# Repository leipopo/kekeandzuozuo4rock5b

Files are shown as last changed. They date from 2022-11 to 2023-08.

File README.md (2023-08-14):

# kekeandzuozuo4rock5b 

## CAD源文件，链接 https://a360.co/3OjdNzo

## 给RockPi 5B V1.4硬件版本用的壳壳 （模型以CAD文件为准,stl可能更新不及时）

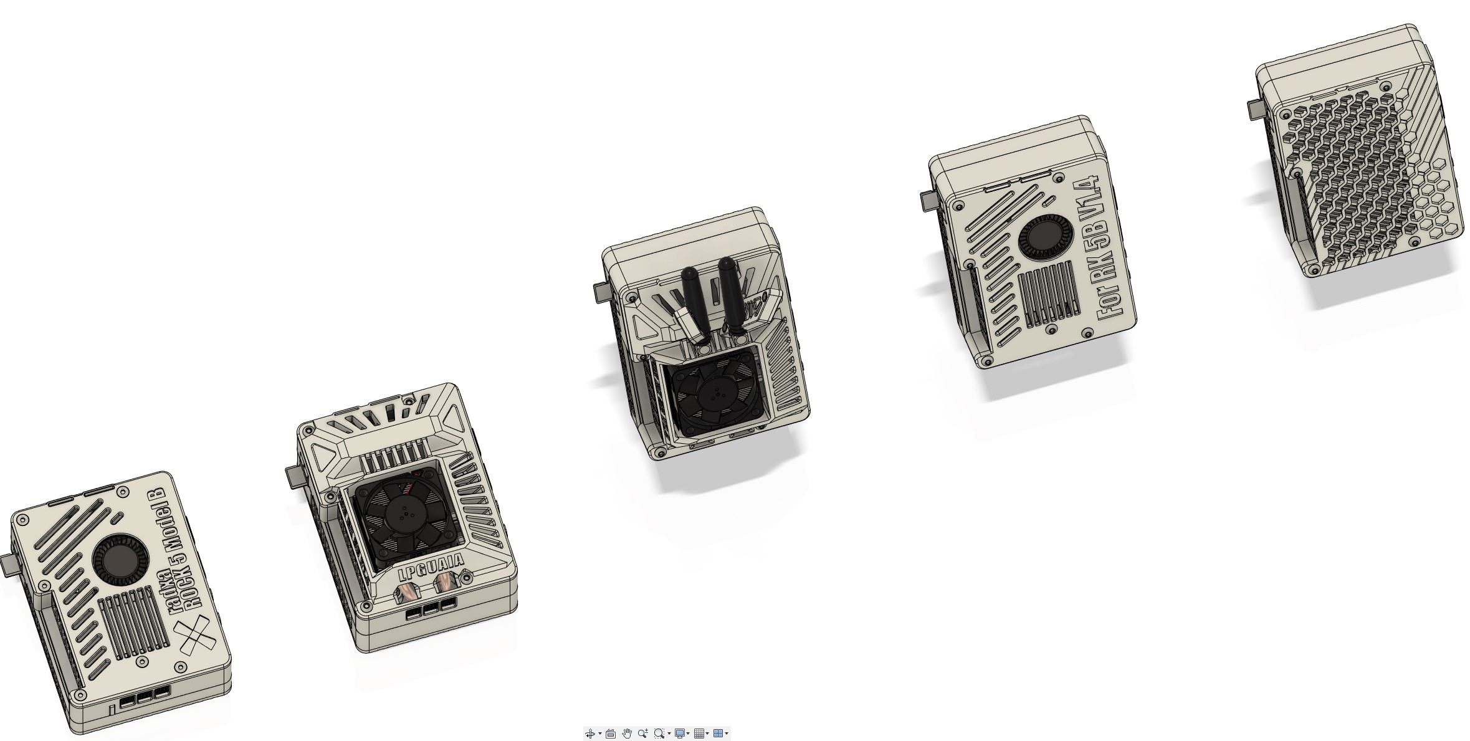
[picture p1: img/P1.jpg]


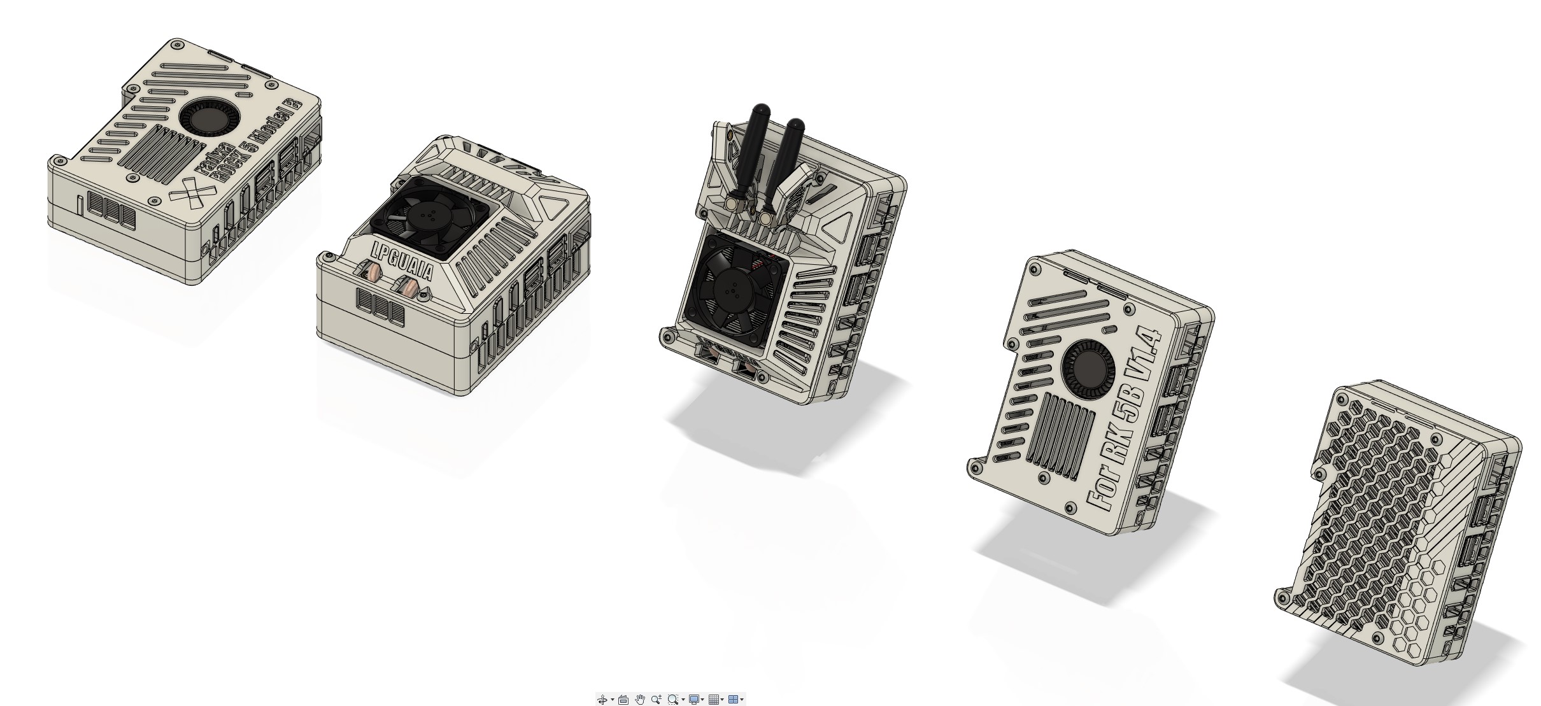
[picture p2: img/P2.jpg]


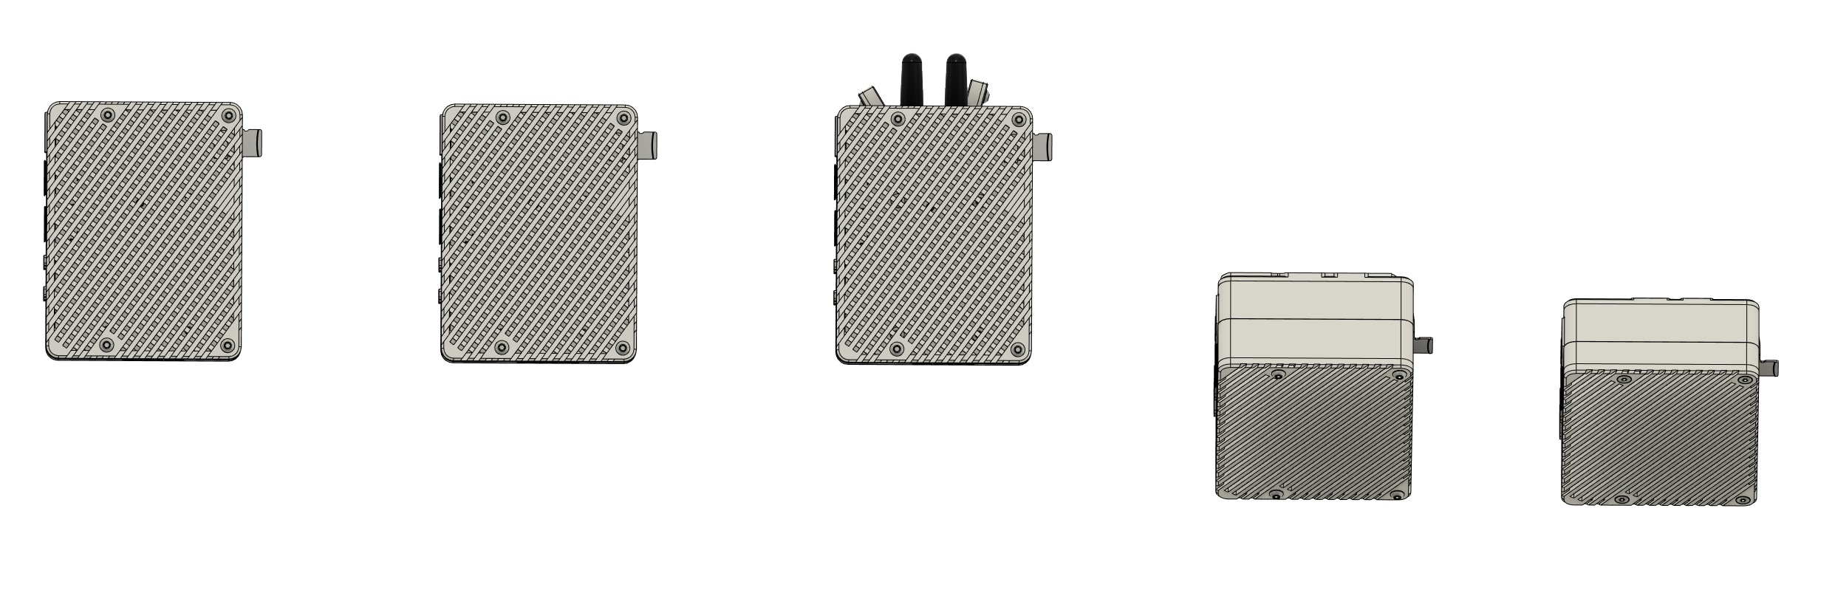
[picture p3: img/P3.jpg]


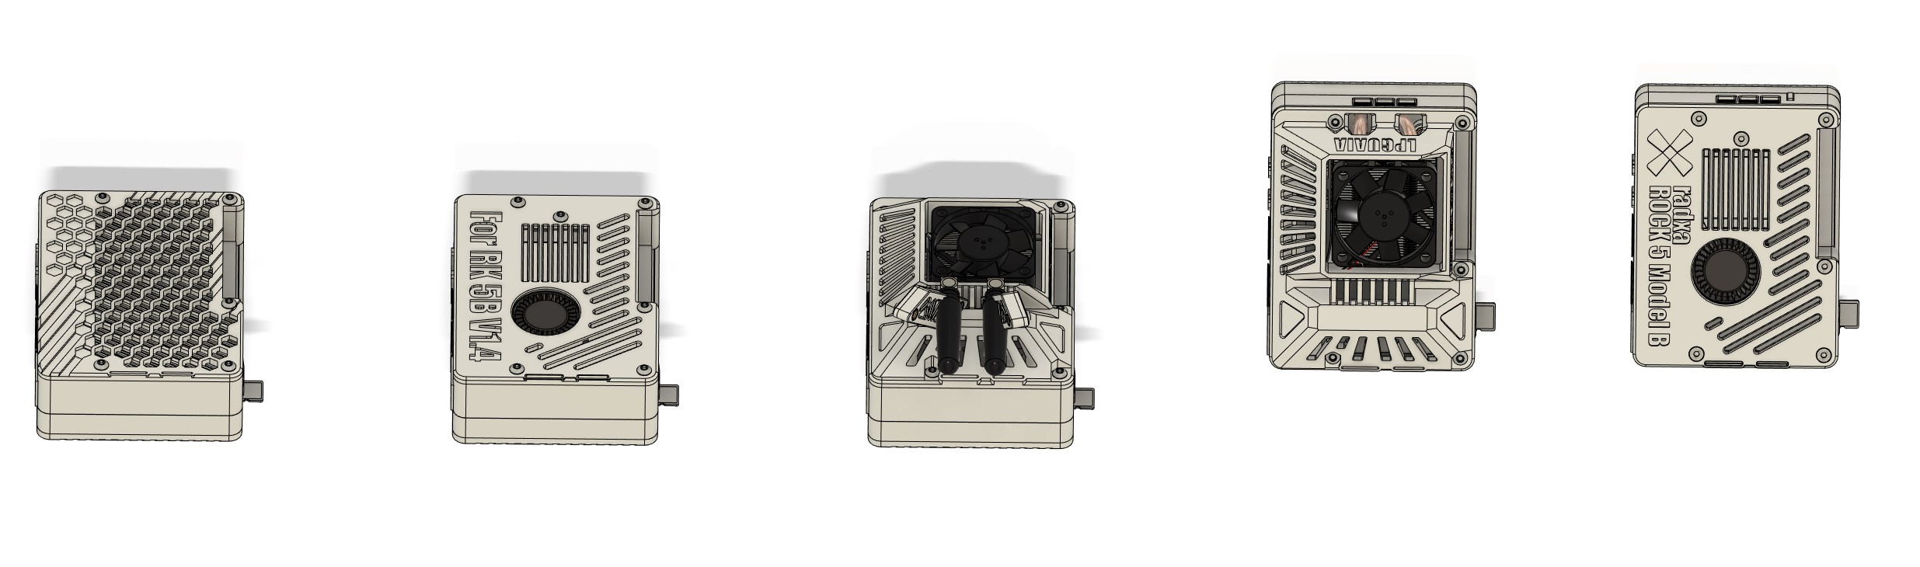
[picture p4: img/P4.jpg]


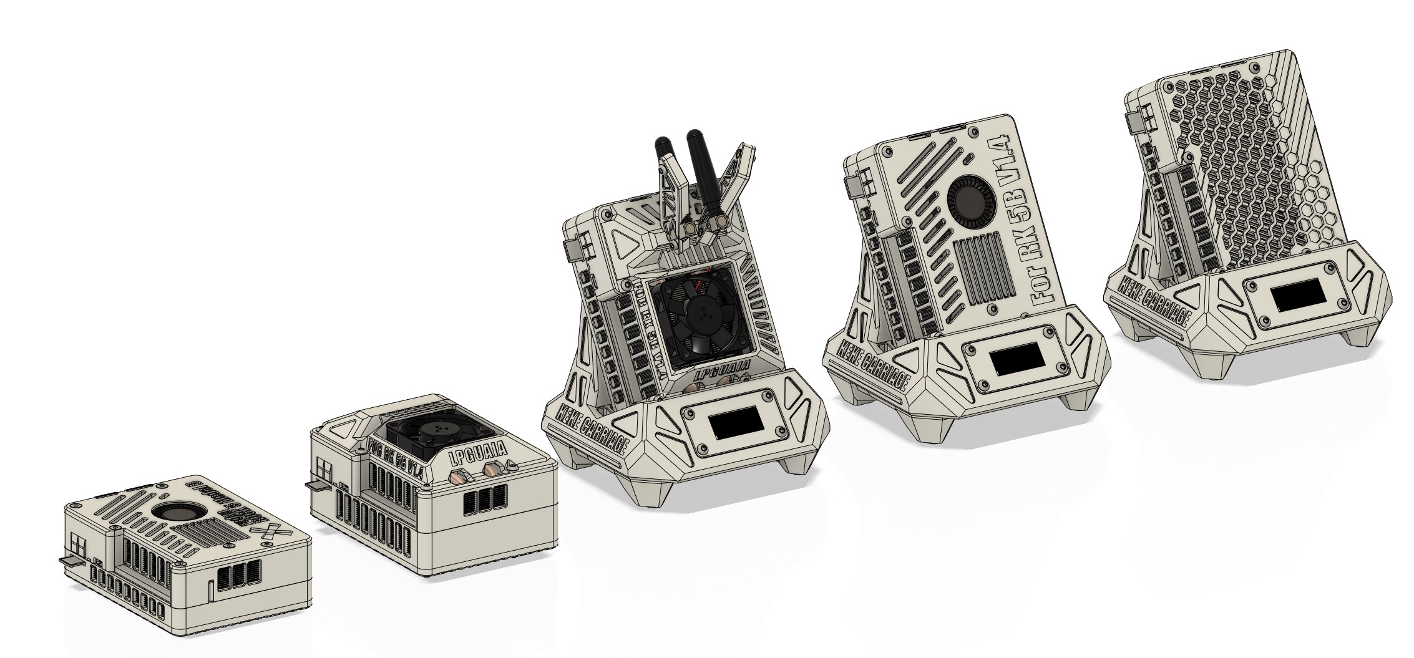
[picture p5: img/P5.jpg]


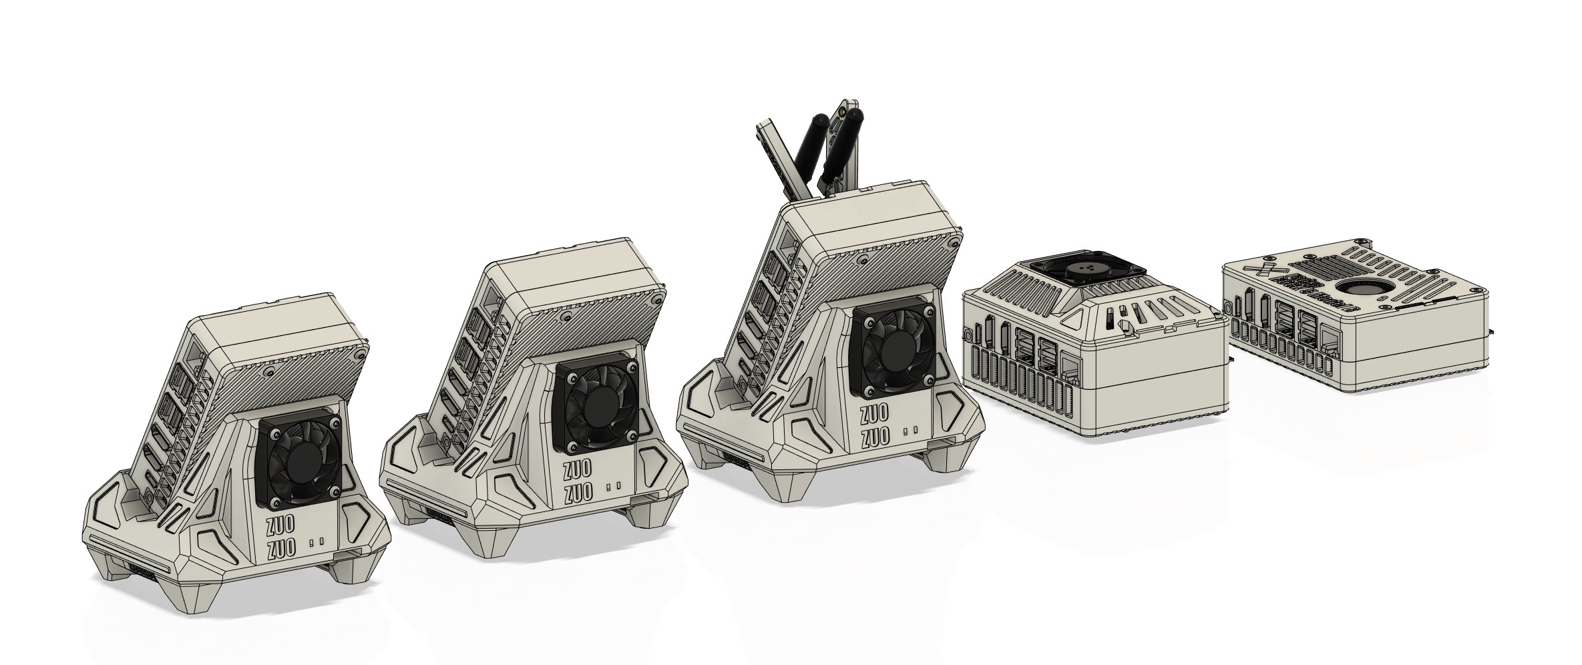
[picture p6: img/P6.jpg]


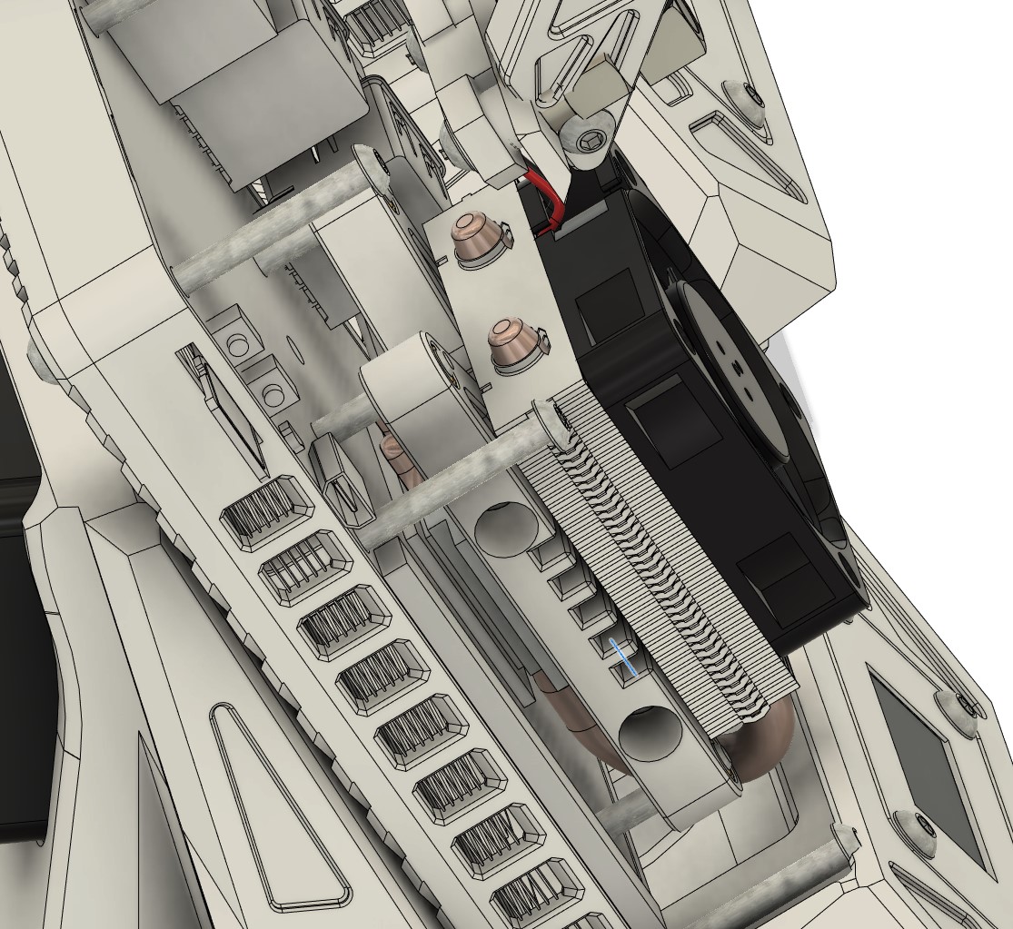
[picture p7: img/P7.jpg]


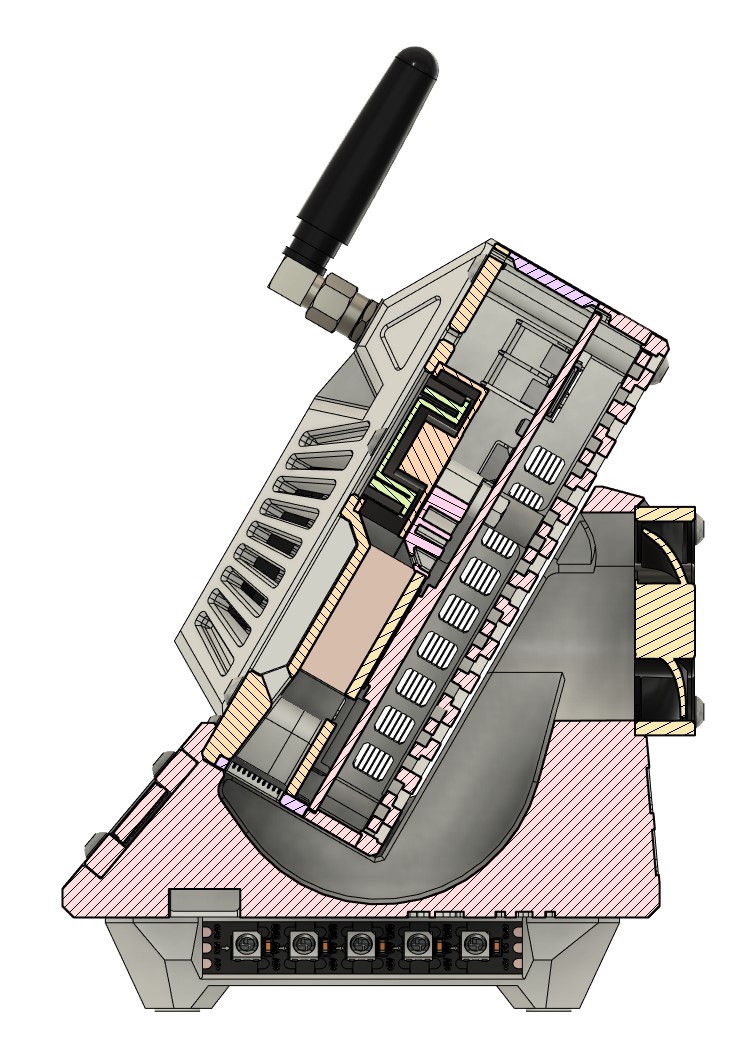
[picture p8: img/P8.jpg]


买不起台灯不太好打光就举着拍吧

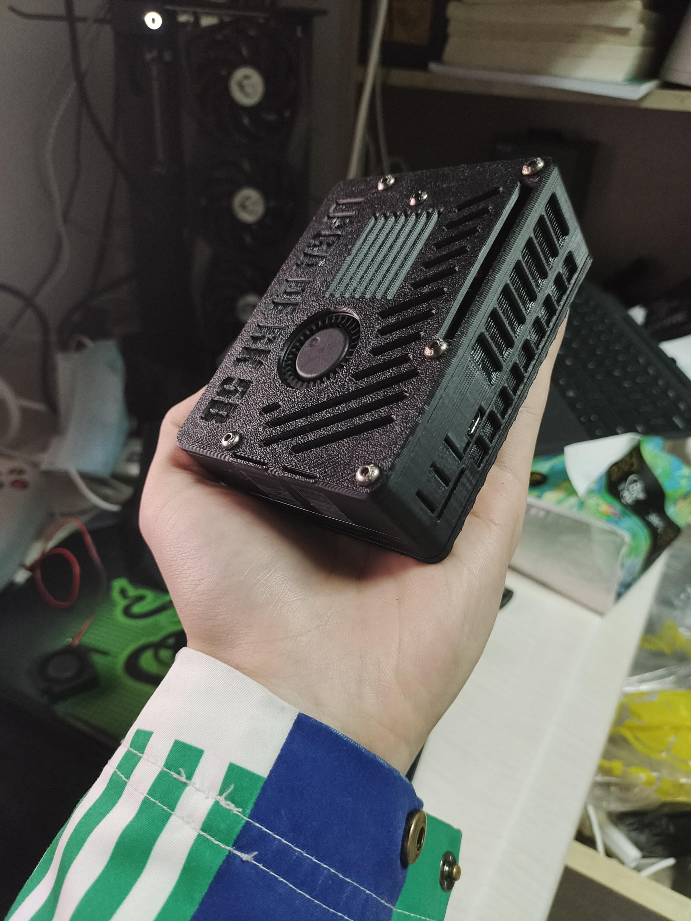
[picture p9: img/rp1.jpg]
rp1 图


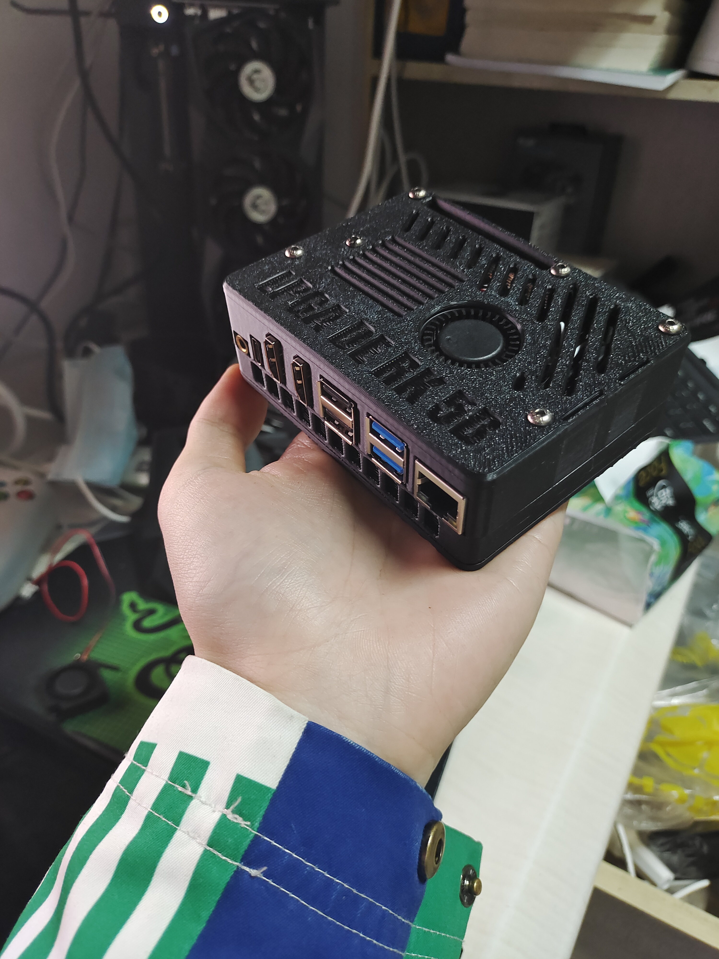
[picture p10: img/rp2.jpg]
rp2 图


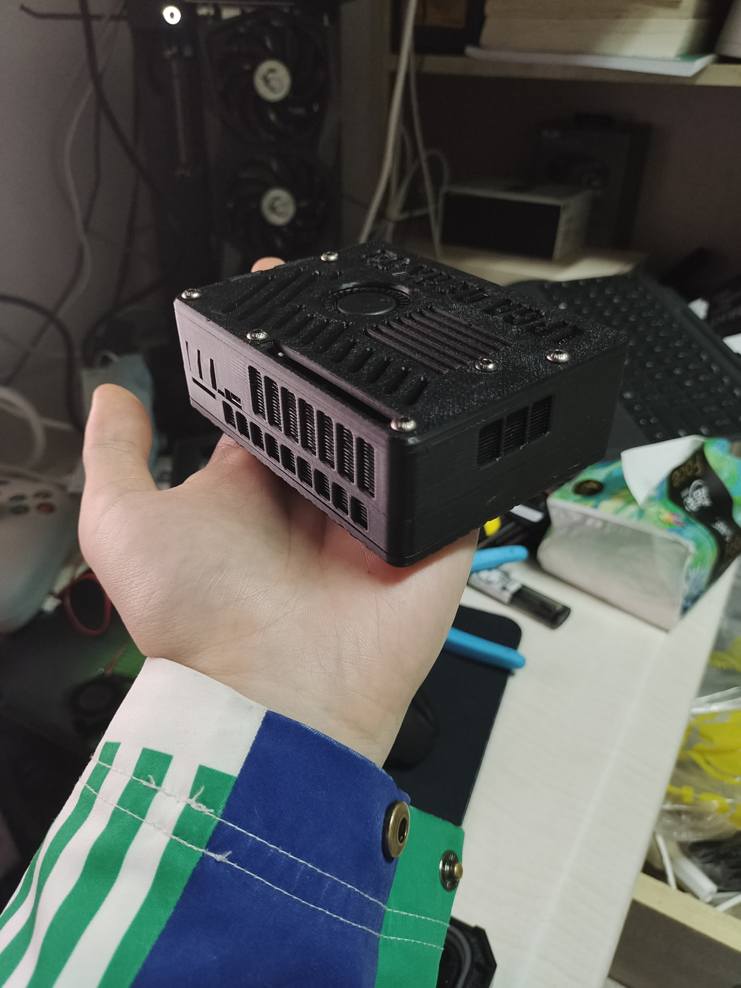
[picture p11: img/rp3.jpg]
rp3 图


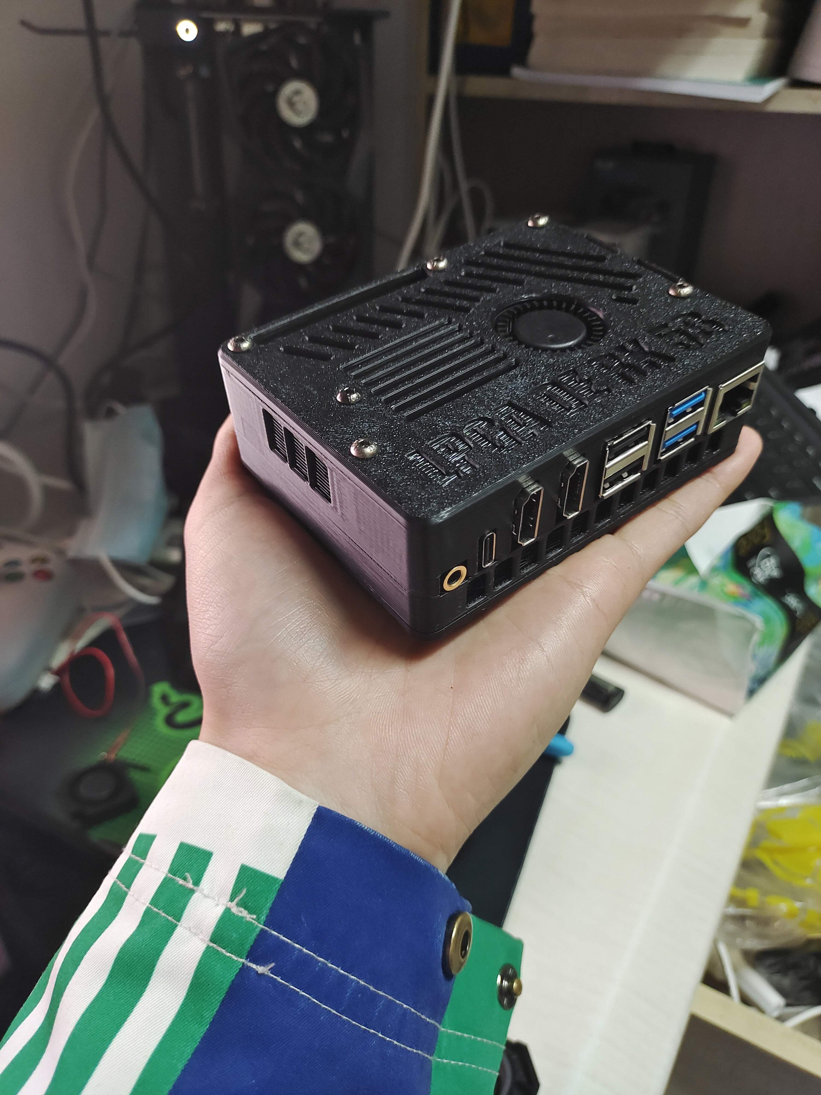
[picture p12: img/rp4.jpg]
rp4 图


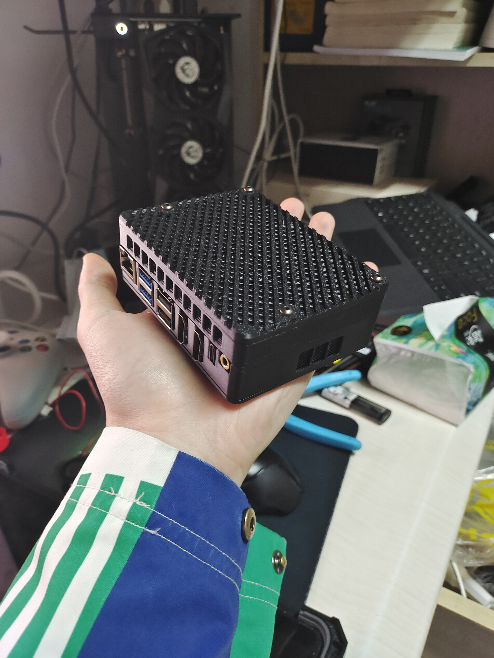
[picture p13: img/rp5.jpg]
rp5 图


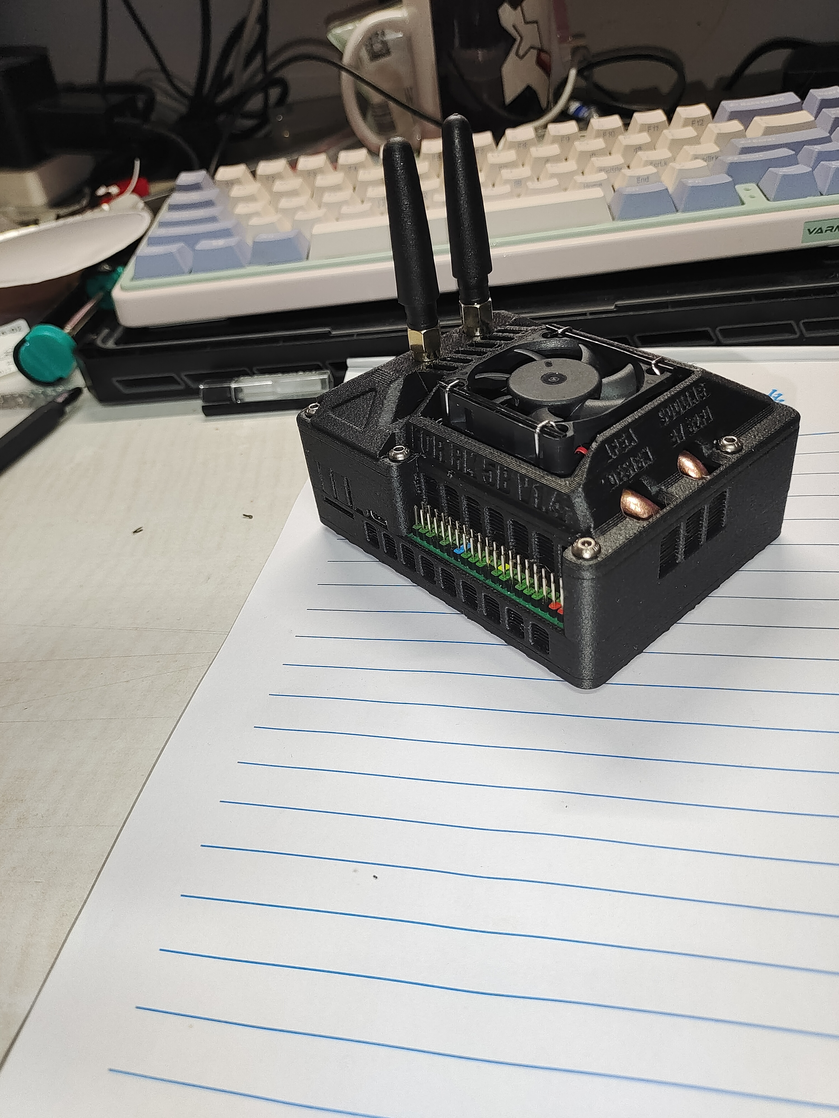
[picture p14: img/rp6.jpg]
rp6 图


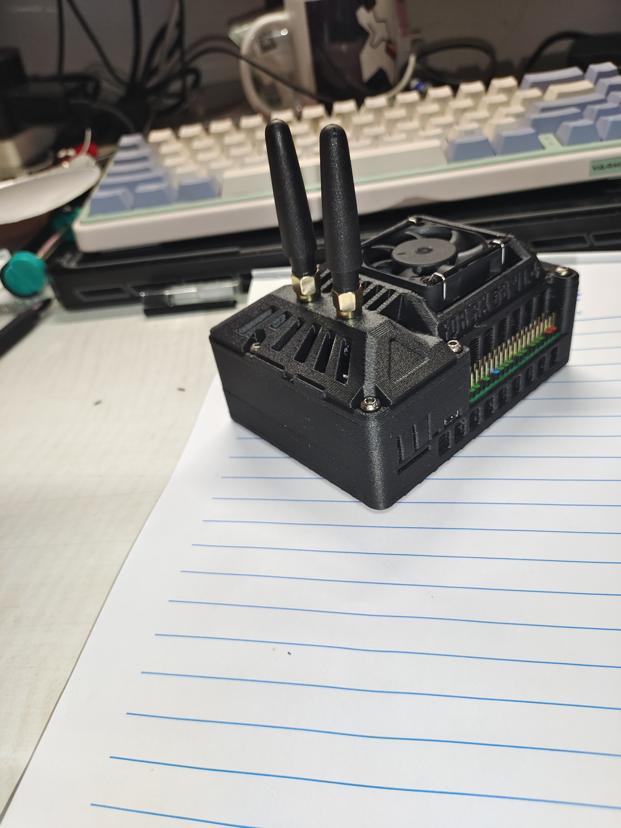
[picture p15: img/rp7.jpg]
rp7 图


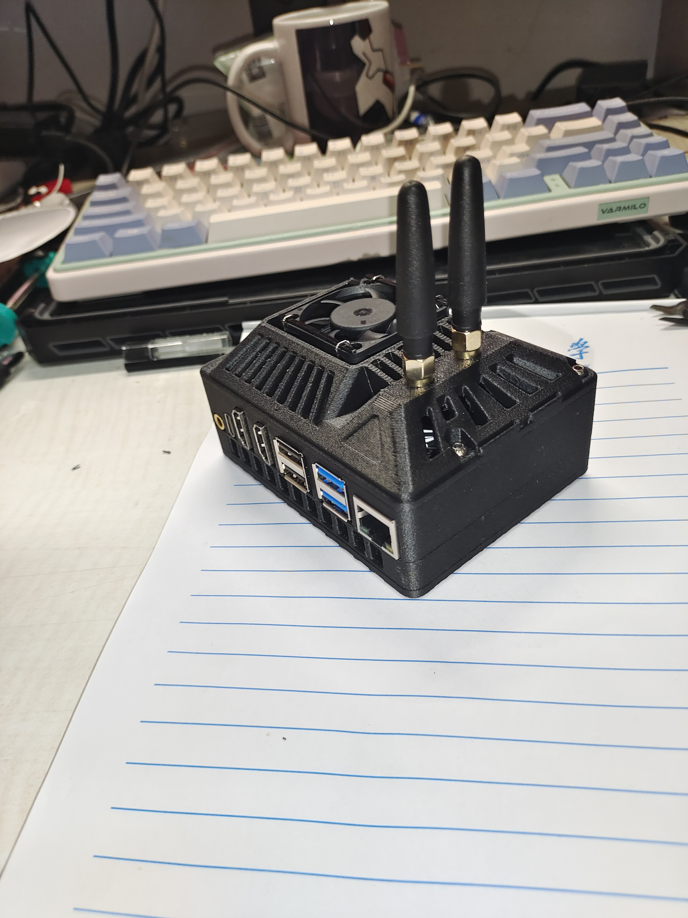
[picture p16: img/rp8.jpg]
rp8 图


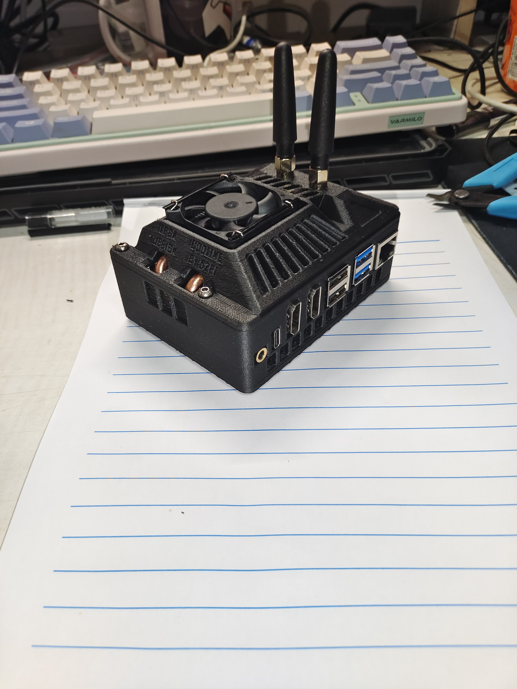
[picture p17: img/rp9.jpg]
rp9 图


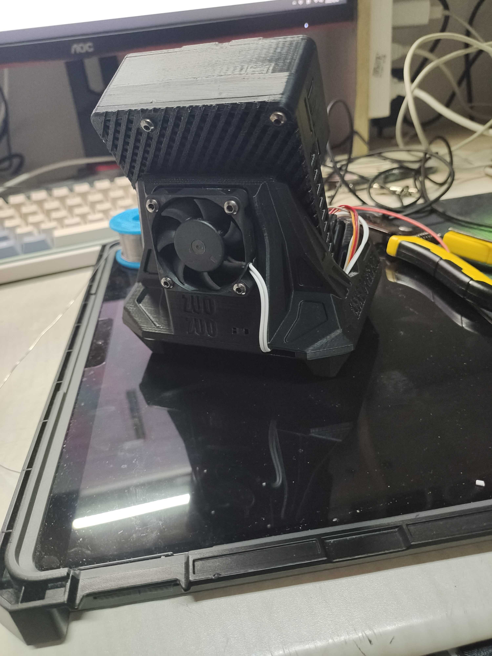
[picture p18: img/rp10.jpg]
rp10 图


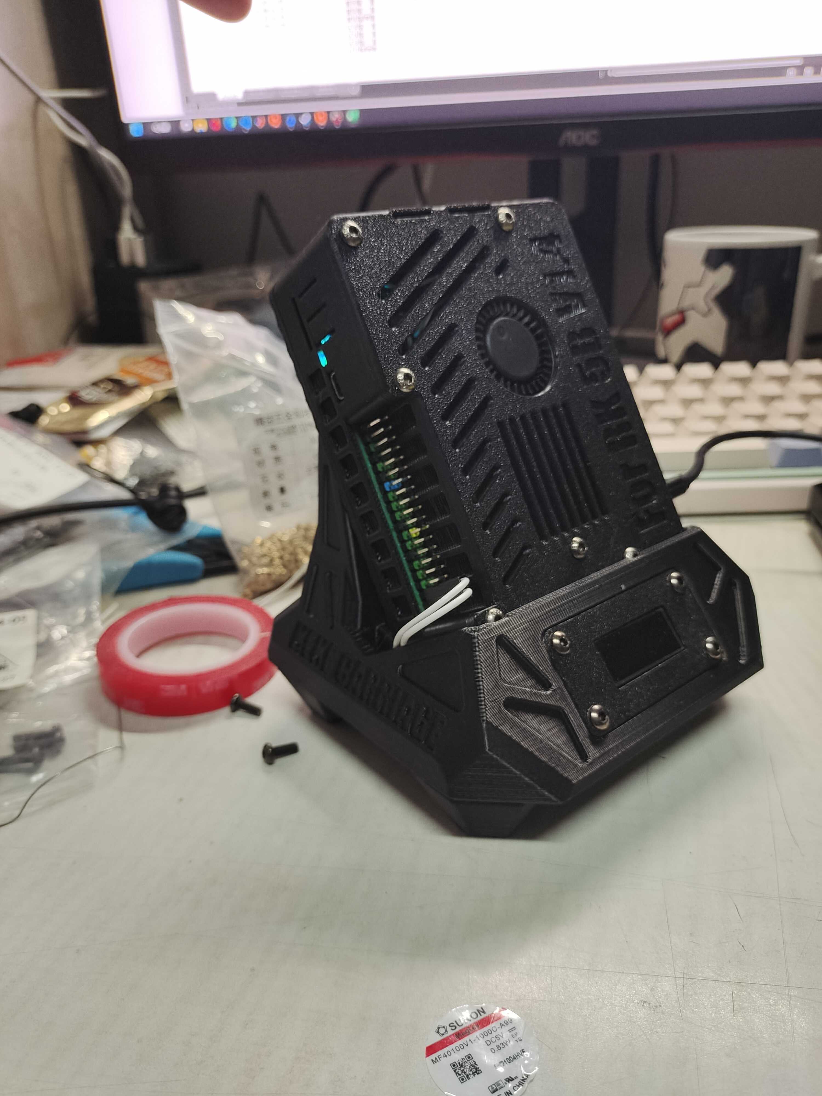
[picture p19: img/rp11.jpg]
rp11 图


## 物料购买注意事项

1. 散热鳍片25x25x11；

2. 滚花螺母尺寸M3 H4 D4.5
滚花螺母尺寸M3 H4 D4.5
滚花螺母尺寸M3 H4 D4.5
重要的事情嗦三遍（用外径5的大了容易顶到附近的小电容）；

3. 螺丝M3 长度8——25买齐 还需要一个六角螺母（散热片版本）；

4. 摄像头，屏幕，GPIO排针都需要线材引出；

5. 除了下压式散热版本，其他版本无线网卡需要用粘上去的那种天线；

6. 散热片版本如果使用硅脂导热，需要购买3M的VHB双面胶贴在上盖压住散热片的位置，如上面最后一张图红色部分所示。屏幕的固定同样需要VHB，因为我担心这个小屏幕尺寸公差比较大所以游隙留的比较大；

7. WS2812灯条买100灯珠一米的，贴在脚撑内侧空白处，两侧的串联，应该可以一边五个，CAD图里用的60灯珠的示意一下；

8. 需要脚垫可淘宝搜索“橡胶脚垫 机箱仪器”，然后买内径3mm外径11mm及以下的如下图

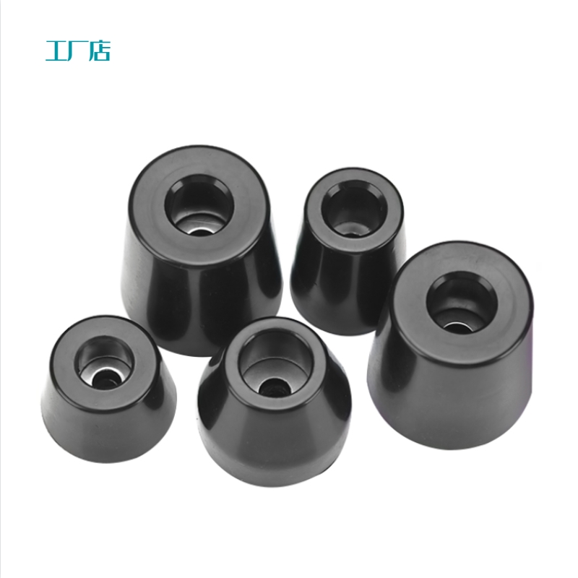
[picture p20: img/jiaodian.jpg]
脚垫图


## FDM注意事项（实时更新，0.4线宽，0.2层高）

使用壳壳需要打印“壳壳基础打印件”中的“上框”、“下框”、“下盖”或者“壳壳基础打印件”中“改件”中的同名文件。此外还需要根据购买的散热组件来打印相应的其他结构,stl文件分别放置在“散热片散热”、“官方散热器散热”以及“下压式散热”中。

树莓派上盖有有外置天线/无外置天线两个版本，有天线上盖可以上小耳朵或者盖板代替外置天线，小耳朵里面可以塞一个内置天线

带maskrom按钮的上框略有突起但也可以放上底座

## 关于风扇脚本（自用）

需要sudo权限，要自启的话需要自行操作一下。

拉取完整仓库：

```cd ~```

```git clone https://ghproxy.com/https://github.com/leipopo/kekeandzuozuo4rockpi5b```

运行风扇脚本：

```cd $HOME/kekeandzuozuo4rockpi5b/ctrlscript/fanctrl/build```

```sudo ./fanctrl```

### 调整风扇初始化文件参数

不建议修改此文件排版

### 参数命名及作用

![风扇原理示意图](/img/fan.jpg "风扇原理示意图")

1. reset 调整参数后需要调整此参数为1

2. obj 温控对象，暂时只有soc

3. exp_temp 期望温度

4. wall_temp 上限温度

5. lowpower_temp 进入低速区温度

6. fanon_temp 风扇开启温度
 
7. fan_maxpwm 风扇极限转速时pwm占空值

8. fan_minpwm 风扇起转时的pwm占空值

9. fan_maxpower 风扇最大功率 0--1.f

10. fan_mod 1.线性控制，2.手动控制 3.开关控制
 
11. fan_pwm="0" 手动控制时给的pwm占空值

12. pwm_period="10000" pwm周期值

13. pwm_chip="/pwmchip15" pwm设备号

14. pwm_channel="/pwm0" pwm设备下通道号

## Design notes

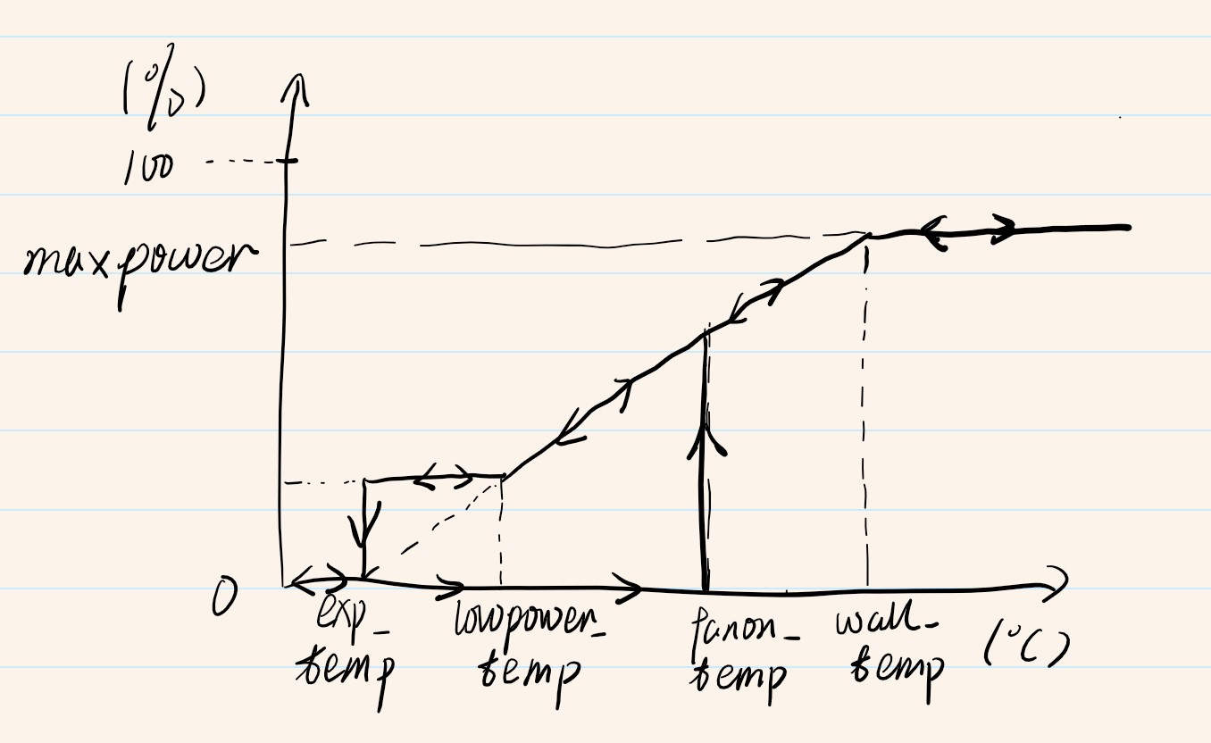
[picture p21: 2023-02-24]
img/fan.jpg

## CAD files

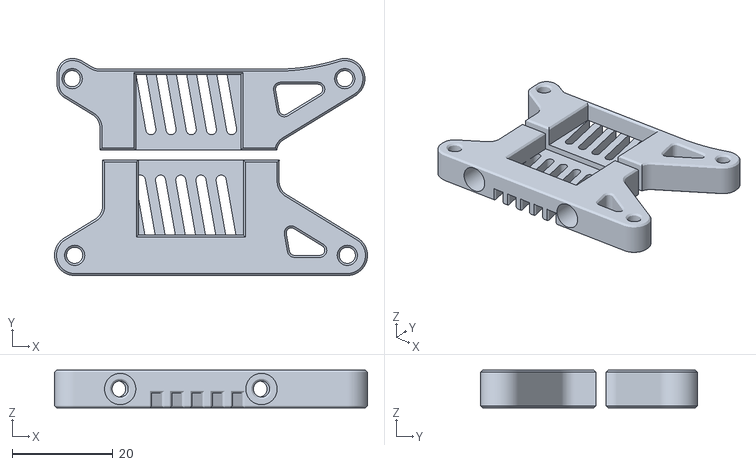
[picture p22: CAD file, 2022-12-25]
stl/下压式散热/扣具.stl
62.0 x 43.0 x 7.50

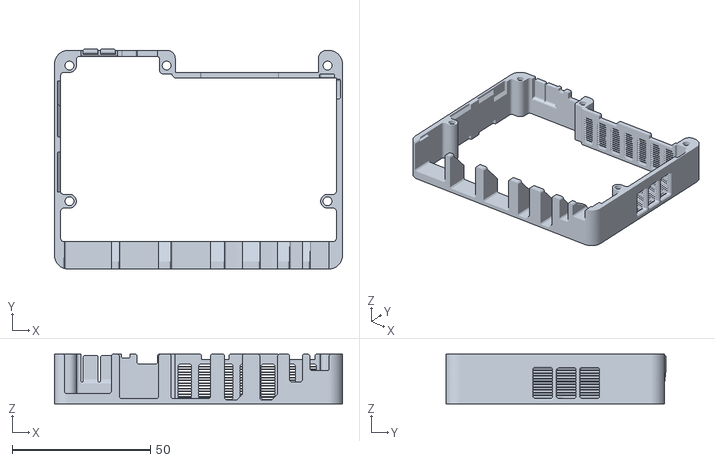
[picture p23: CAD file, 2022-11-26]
stl/壳壳基础打印件/上框.stl
104.0 x 79.5 x 18.0

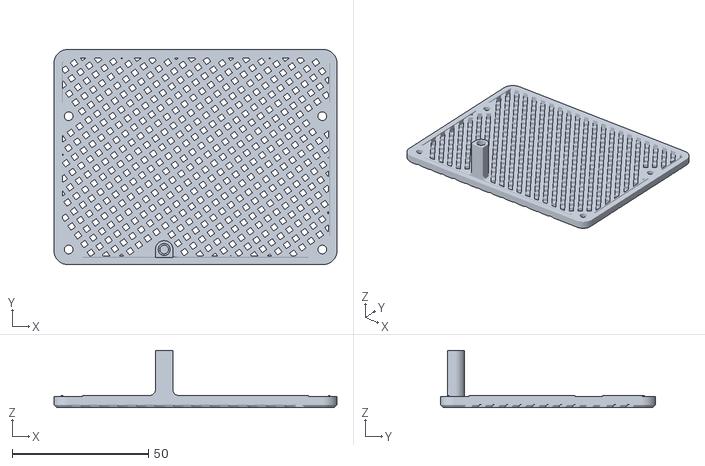
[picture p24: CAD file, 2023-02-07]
stl/壳壳基础打印件/改件/下盖加高.stl
104.0 x 79.0 x 21.0

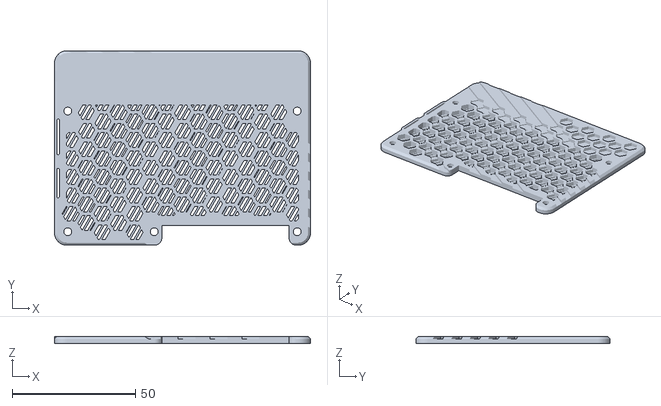
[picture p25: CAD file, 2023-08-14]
stl/官方散热器散热/上盖FE_密集网格.stl
104.0 x 79.0 x 3.00

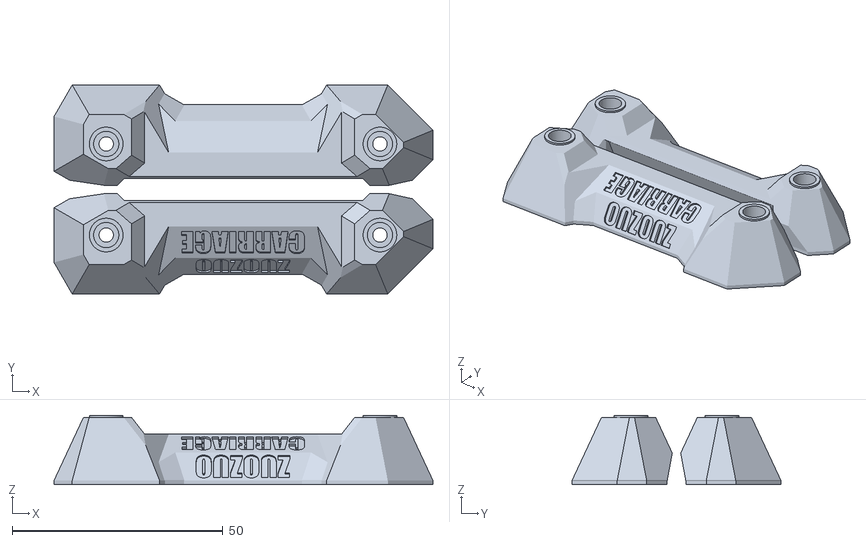
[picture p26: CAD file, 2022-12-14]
stl/座座/rgb脚撑.stl
90.0 x 49.6 x 16.5

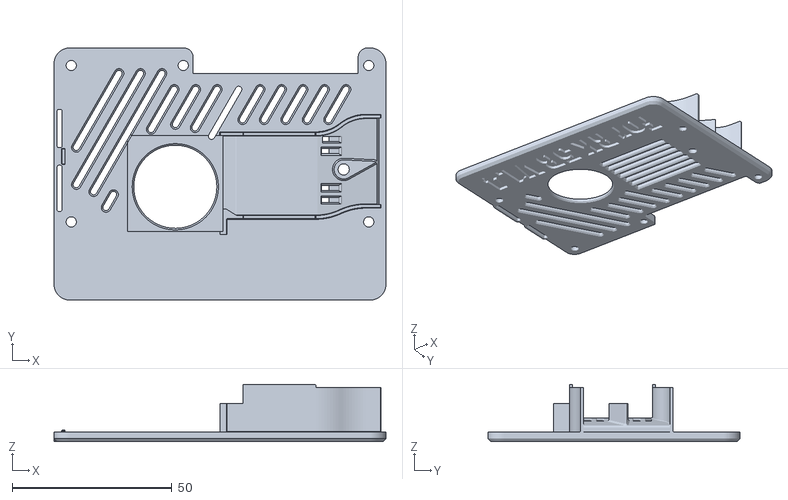
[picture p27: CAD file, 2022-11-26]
stl/散热片散热/上盖.stl
104.0 x 79.0 x 18.0

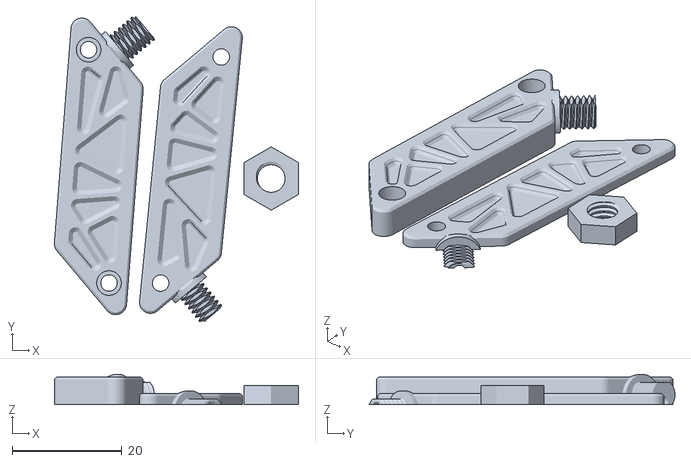
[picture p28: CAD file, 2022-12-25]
stl/下压式散热/耳朵.stl
44.6 x 55.8 x 5.50

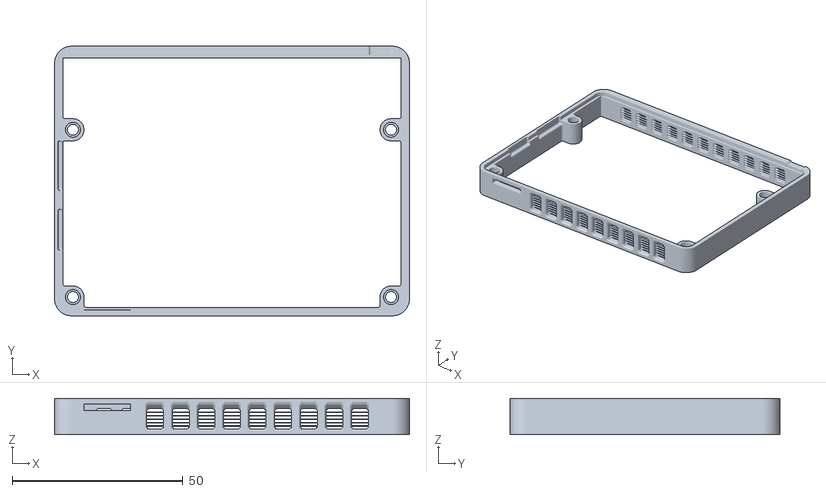
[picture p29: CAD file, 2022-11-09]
stl/壳壳基础打印件/下框.stl
104.0 x 79.0 x 10.6

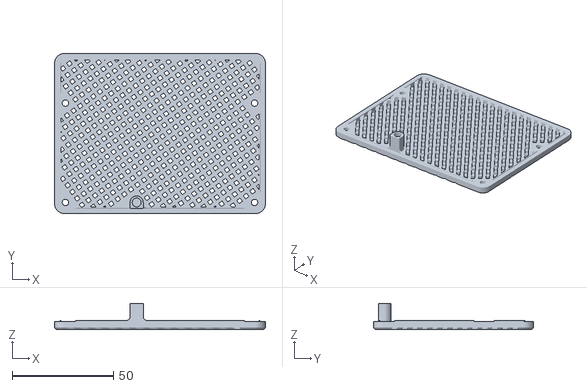
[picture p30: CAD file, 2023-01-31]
stl/壳壳基础打印件/改件/下盖沉头螺丝版本.stl
104.0 x 79.0 x 13.0

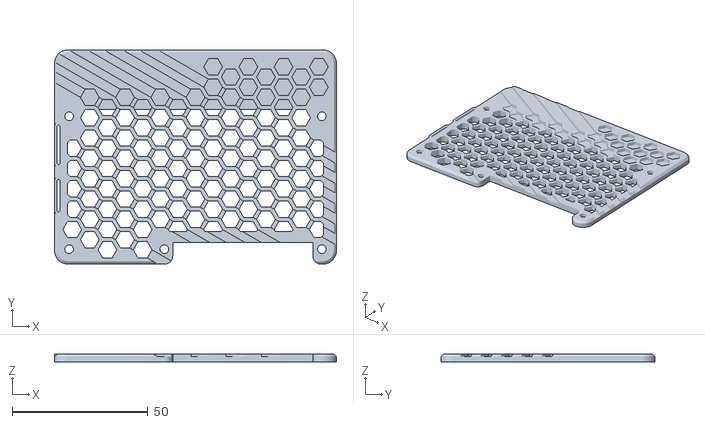
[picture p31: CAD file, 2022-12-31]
stl/官方散热器散热/上盖FE.stl
104.0 x 79.0 x 3.00

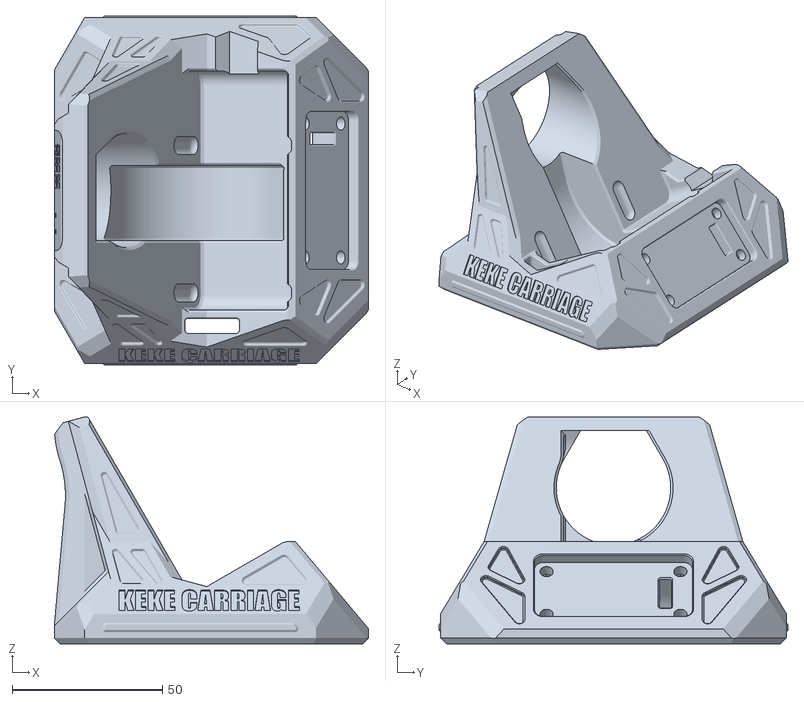
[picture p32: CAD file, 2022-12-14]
stl/座座/底座.stl
104.5 x 116.0 x 75.4

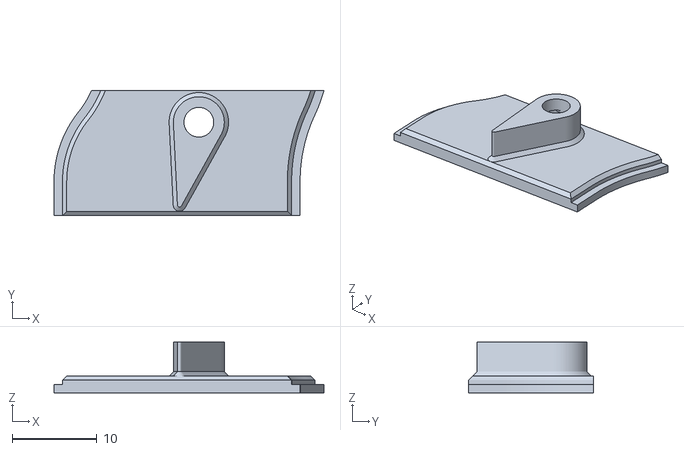
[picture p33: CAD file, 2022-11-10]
stl/散热片散热/风道下挡板.stl
31.8 x 14.8 x 6.00

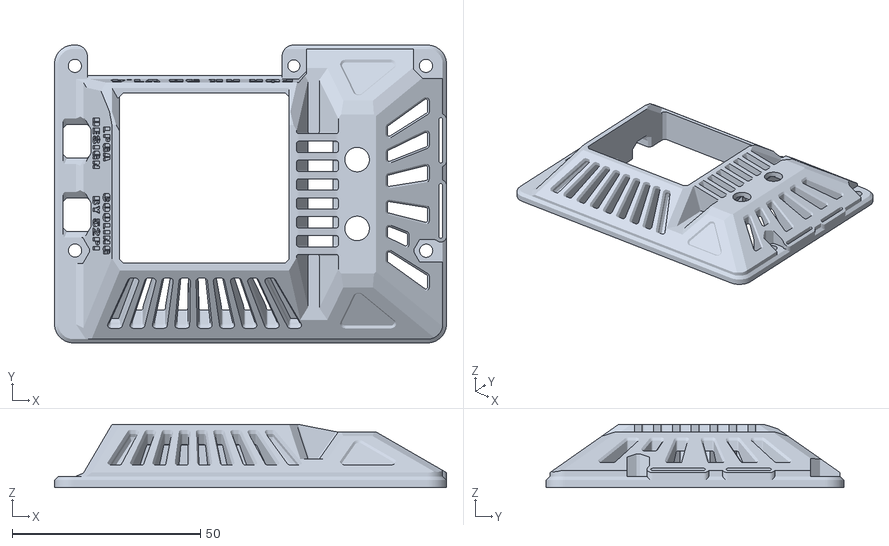
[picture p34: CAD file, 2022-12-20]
stl/下压式散热/上盖.stl
104.0 x 79.0 x 16.8

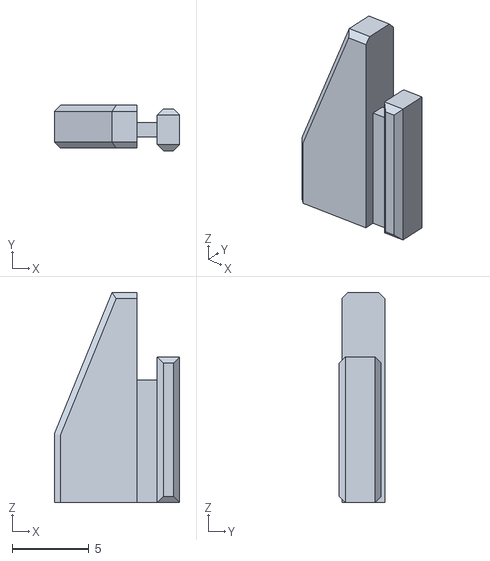
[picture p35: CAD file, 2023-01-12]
stl/壳壳基础打印件/改件/maskrom按钮.stl
8.18 x 2.97 x 13.7

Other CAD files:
stl/散热片散热/改件/上盖沉头螺丝版本.stl
stl/壳壳基础打印件/下盖.stl
stl/座座/屏幕盖.stl
stl/散热片散热/风扇座.stl
stl/壳壳基础打印件/改件/上框withmaskrom按钮.stl
stl/壳壳基础打印件/改件/下框加高.stl

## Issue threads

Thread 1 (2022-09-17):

能增加一个0.96寸oled位置吗

FantasyGmm, 2022-09-17:
能不能加个0.9寸长条oled的屏位置啊，可以显示一些信息，程序方便等我板子到手了我可以写一个
用蓝图风扇噪音大不大啊，之前买过动平衡很差，噪音很大，直接丢了

leipopo, 2022-09-17:
屏幕等我淘宝一下看看具体尺寸，应该也许能加但是线肯定不会太好走。鹏达蓝图的低转速3010不太行，要静音的话换一家吧。（我又买了12k转的过两天到了试试

leipopo, 2022-09-17:
能加但是线不会太好走。鹏达蓝图的低转速3010不太行，要静音的话就换一家吧。（我又买了12k转的过两天到了试试

leipopo, 2022-09-17:
我试试在上盖加一个，应该问题不大。

FantasyGmm, 2022-09-18:
4010风扇可以买建准的磁悬浮 声音挺小的 就是风力有点小

leipopo, 2022-09-18:
4010稍微大了点，而且风道要做收口不太好搞

FantasyGmm, 2022-09-18:
这个风道有用吗，我看这四周孔挺多的，风不会走其他地方漏出去吗

FantasyGmm, 2022-09-18:
用的是普通直吹风扇，还是涡轮扇侧出风的

FantasyGmm, 2022-09-18:
看了下文件，感觉可以把字取消了，然后风扇换成4010，正好旁边加一个长条的oled

leipopo, 2022-09-19:
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

4010稍微太大了点。。oled已经扣出来了明天到了测一测

leipopo, 2022-10-23:
我准备做个5b的散热座，60/90的大风扇从下吹风给ssd和整个pcb散热，然后在那个座子上开这个屏幕口子，就先关掉这个issue了

FantasyGmm, 2022-10-25:
> 我准备做个5b的散热座，60/90的大风扇从下吹风给ssd和整个pcb散热，然后在那个座子上开这个屏幕口子，就先关掉这个issue了

好，等大佬了，顺便做高个树莓派冰塔下压兼容的，盖板吧

Closed 2022-10-23.

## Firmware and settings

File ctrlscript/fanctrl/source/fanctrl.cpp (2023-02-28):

#include "fanctrl.hpp"

using namespace std;

void writefile(const char *path, string data)
{
    ofstream file;
    file.open(path, ios::out);
    file << data;
    file.close();
}

string readfile(const char *path)
{
    ifstream file;
    file.open(path, ios::in);
    string data;
    file >> data;
    file.close();
    return data;
}

void string2char(string str, char *ch)
{
    int i;
    for (i = 0; i < str.length(); i++)
    {
        ch[i] = str[i];
    }
    ch[i] = '\0';
}

void FAN ::readconfigfile(const char *path)
{
    fstream file;
    file.open(path, ios::in | ios::out);
    int begin, end;
    string line;
    getline(file, line);
    begin = line.find_first_of('"');
    end = line.find_last_of('"');

    if (line.substr(begin + 1, end - begin - 1) == "1")
    {
        file.seekp(begin + 1, ios::beg);
        file.write("0", 1);
        file.close();
        file.open(path, ios::in);
        while (!file.eof())
        {
            getline(file, line);
            end = line.find("=");
            string item = line.substr(0, end);
            if (item == "obj")
            {
                begin = line.find_first_of('"');
                end = line.find_last_of('"');
                string obj_temp = line.substr(begin + 1, end - begin - 1);
                if (obj_temp == "soc")
                {
                    this->obj = soc;
                }
                // else if(obj_temp=="ssd")
                // {
                //     this->obj=ssd;
                // }
            }
            else if (item == "exp_temp")
            {
                begin = line.find_first_of('"');
                end = line.find_last_of('"');
                this->exp_temp = stof(line.substr(begin + 1, end - begin - 1));
            }
            else if (item == "wall_temp")
            {
                begin = line.find_first_of('"');
                end = line.find_last_of('"');
                this->wall_temp = stof(line.substr(begin + 1, end - begin - 1));
            }
            else if (item == "lowpower_temp")
            {
                begin = line.find_first_of('"');
                end = line.find_last_of('"');
                this->lowpower_temp = stof(line.substr(begin + 1, end - begin - 1));
            }
            else if (item == "fanon_temp")
            {
                begin = line.find_first_of('"');
                end = line.find_last_of('"');
                this->fanon_temp = stof(line.substr(begin + 1, end - begin - 1));
            }
            else if (item == "fan_maxpwm")
            {
                begin = line.find_first_of('"');
                end = line.find_last_of('"');
                this->fan_maxpwm = stoi(line.substr(begin + 1, end - begin - 1));
            }
            else if (item == "fan_minpwm")
            {
                begin = line.find_first_of('"');
                end = line.find_last_of('"');
                this->fan_minpwm = stoi(line.substr(begin + 1, end - begin - 1));
            }
            else if (item == "fan_maxpower")
            {
                begin = line.find_first_of('"');
                end = line.find_last_of('"');
                this->fan_maxpower = stof(line.substr(begin + 1, end - begin - 1));
            }
            else if (item == "fan_mod")
            {
                begin = line.find_first_of('"');
                end = line.find_last_of('"');
                this->fan_mod = stoi(line.substr(begin + 1, end - begin - 1));
            }
            else if ((item == "fan_pwm") && this->fan_mod == manualmod)
            {

                begin = line.find_first_of('"');
                end = line.find_last_of('"');
                this->fan_pwm = stoi(line.substr(begin + 1, end - begin - 1));
            }
            else if (item == "pwm_period")
            {
                begin = line.find_first_of('"');
                end = line.find_last_of('"');
                this->pwm_period = stoi(line.substr(begin + 1, end - begin - 1));
            }
            else if (item == "pwm_chip")
            {
                begin = line.find_first_of('"');
                end = line.find_last_of('"');
                string2char(line.substr(begin + 1, end - begin - 1), this->pwm_chip);
                // cout << this->pwm_chip << endl;
            }
            else if (item == "pwm_channel")
            {
                begin = line.find_first_of('"');
                end = line.find_last_of('"');
                string2char(line.substr(begin + 1, end - begin - 1), this->pwm_channel);
                // cout << this->pwm_channel << endl;
            }
        }
    }
    file.close();
}

void init(const char *path, FAN *fan)
{
    fstream file;
    file.open(path, ios::in | ios::out);
    int begin, end;
    string line;
    getline(file, line);
    begin = line.find_first_of('"');
    end = line.find_last_of('"');
    file.seekp(begin + 1, ios::beg);
    file.write("1", 1);
    file.close();

    fan->readconfigfile(path);

    const char *chip = fan->pwm_chip;
    const char *channel = fan->pwm_channel;
    string const &finalpath1 = pwm_path + string(chip);
    string finalpath2 = finalpath1 + string(channel);
    string export_path = finalpath1 + "/export";
    string duty_cycle_path = finalpath2 + "/duty_cycle";
    string period_path = finalpath2 + "/period";
    string enable_path = finalpath2 + "/enable";
    string polarity_path = finalpath2 + string("/polarity");

    // cout << export_path << endl;
    string2char(export_path, fan->pwm_export_path);
    // cout << this->pwm_export_path << endl;
    string2char(duty_cycle_path, fan->pwm_dutycycle_path);
    string2char(period_path, fan->pwm_period_path);
    string2char(enable_path, fan->pwm_enable_path);
    string2char(polarity_path, fan->pwm_polarity_path);

    // cout << this->pwm_polarity_path << endl;

    if (fan->obj == soc)
    {
        string temp = string(soc_temp_path);
        string2char(temp, fan->objtemp_path);
    }
    // else if(this->obj==ssd)
    // {
    //     this->objtemp_path=ssd_temp_path;
    // }
    writefile(fan->pwm_export_path, "0");
    usleep(1000 * 1000);
    writefile(fan->pwm_dutycycle_path, to_string(fan->fan_pwm));
    usleep(1000 * 10);
    writefile(fan->pwm_period_path, to_string(fan->pwm_period));
    usleep(1000 * 10);
    writefile(fan->pwm_enable_path, "0");
    usleep(1000 * 10);
    writefile(fan->pwm_polarity_path, "normal");
    fan->switcher = false;
    fan->boosttime=0;
}

int FAN::power2pwm(float power)
{
    int pwm = (this->fan_maxpwm - this->fan_minpwm) * power * this->fan_maxpower + this->fan_minpwm;
    return pwm;
}

void FAN::boost()
{
    writefile(pwm_dutycycle_path, to_string(this->pwm_period));
}

void FAN::pwmcalc()
{
    string temp = readfile(this->objtemp_path);
    this->obj_temp = stof(temp) / 1000.f;
    switch (this->fan_mod)
    {
    case switchmod:
    {
        if (this->obj_temp > this->wall_temp)
        {
            this->boost();
            this->fan_pwm = this->power2pwm(this->fan_maxpower);
        }
        else if (this->obj_temp < this->exp_temp)
        {
            this->fan_pwm = 0;
        }
    }
    break;

    case linermod:
    {
        if (this->obj_temp > this->fanon_temp)
        {
            if (this->switcher == false)
            {
                this->boost();
                if (this->boosttime == 0)
                {
                    writefile(this->pwm_enable_path, "1");
                }
                this->boosttime++;
            }
            if (this->boosttime == boosttime_max)
            {
                this->boosttime = 0;
                this->switcher = true;
            }
        }
        if (this->obj_temp > this->lowpower_temp)
        {
            if (this->switcher == true)
            {
                this->fan_pwm = this->power2pwm((this->obj_temp - this->exp_temp) / (this->wall_temp - this->exp_temp));
            }
        }
        else if (this->obj_temp < this->exp_temp)
        {
            this->fan_pwm = 0;
            writefile(this->pwm_enable_path, "0");
            this->switcher = false;
        }
    }
    break;

    default:
        break;
    }
}

void FAN::setpwmdev()
{
    string data;
    data = to_string(this->fan_pwm);
    writefile(this->pwm_dutycycle_path, data);
}

int main()
{
    // FAN socfan, ssdfan;
    FAN socfan;
    init(soc_fan_configfile_path, &socfan);
    // init(ssd_fan_configfile_path, &ssdfan);
    while (1)
    {
        socfan.readconfigfile(soc_fan_configfile_path);
        // ssdfan.readconfigfile(ssd_fan_configfile_path);
        socfan.pwmcalc();
        // ssdfan.pwmcalc();
        socfan.setpwmdev();
        // ssdfan.setpwmdev();
        usleep(20 * 1000);
    }
}

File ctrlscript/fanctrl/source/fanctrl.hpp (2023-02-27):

#include <fstream>
#include <iostream>
#include <unistd.h>
#include <math.h>
#include <string.h>
#include <stdio.h>

#define soc_temp_path "/sys/class/thermal/thermal_zone2/temp"
#define pwm_path "/sys/class/pwm"
#define soc_fan_configfile_path "../source/soc_fan_config"
#define ssd_fan_configfile_path "../source/ssd_fan_config"
#define soc 0
#define linermod 1
#define manualmod 2
#define switchmod 3
#define boosttime_max 200

class FAN
{
public:
    bool switcher;
    int boosttime;
    int obj;
    int pwm_period;
    int fan_maxpwm;
    int fan_minpwm;
    int fan_mod;
    int fan_pwm;
    
    float obj_temp;
    float fan_maxpower;
    float exp_temp;
    float wall_temp;
    float lowpower_temp;
    float fanon_temp;

    int power2pwm(float power);
    void readconfigfile(const char *path);
    void pwmcalc();
    void setpwmdev();
    void boost();

    char pwm_chip[16]={'0',};
    char pwm_channel[16]={'0',};

    char objtemp_path[64]={'0',};
    char pwm_dutycycle_path[64]={'0',};
    char pwm_period_path[64]={'0',};
    char pwm_enable_path[64]={'0',};
    char pwm_polarity_path[64]={'0',};
    char pwm_export_path[64]={'0',};
};

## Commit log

2022-09-08 第一版壳壳，未验证
2022-09-08 加了几张图图
2022-09-08 cad版本传错了
2022-09-12 添加了一些镂空和stl，优化了忘了优化的风扇座
    [上框 v13.stl, 上盖 v33.stl, 下框 v14.stl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]
2022-09-13 add pwm ctrlscript for the fan
2022-09-13 改了下桁架的间距，还有控制jio本
    [上框 v13.stl, 上盖 v33.stl, 下框 v14.stl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]
2022-09-13 修改了按键的厚度
2022-09-13 加厚了上框，取消了下盖立柱
2022-09-13 修改了上框接口尺寸
2022-09-14 修改了上框接口处
2022-09-14 装了个螺母
2022-09-15 修正了启动bug
2022-09-16 完全验证
    [上框.stl, 上盖.stl, 下框.stl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]
2022-09-16 更新下盖stl
    [下盖.stl]
2022-09-17 增加开关控制
2022-09-24 修复了上盖漏风的bug
    [上盖.stl]
2022-09-25 修改了FDM加工部分孔预留的公差
2022-09-27 重新传个step
2022-10-13 依照官方v1.42版本pcbCAD对模型进行了较大调整，rt
    [上框.stl, 上盖.stl, 下框.stl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]
2022-10-13 重做了风扇脚本，改动方便点
2022-10-14 修改了一下脚本
2022-10-14 还是改脚本
2022-10-14 写了个大bug修了修
2022-10-23 更新readme
2022-10-23 修改readme
2022-11-04 修改了tf卡槽
    [下框.stl]
2022-11-09 将soc风道分到ram和网卡修改了散热口形状并增加了散热底座
    [上框.stl, 上盖.stl, 下框.stl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]
2022-11-09 修改了一点座子细节
    [上框.stl, 上盖.stl, 下框.stl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]
2022-11-09 修复了风道下挡板沉孔需要支撑的问题
    [风道下挡板.stl]
2022-11-10 修改了风道下挡板和上盖
    [上框.stl, 上盖.stl, 风道下挡板.stl]
2022-11-14 暂时就这样，过段时间再更脚撑和下压式散热器
    [上框.stl]
2022-11-14 增加实物图
2022-11-14 更新图片
2022-11-17 修改将针脚露出
    [上框.stl, 上盖.stl]
2022-11-17 修改了底座
    [底座.stl]
2022-11-17 RGB嘿嘿RGB，驱动等我5B返修回来再写
    [rgb脚撑.stl, 底座.stl]
2022-11-18 修改底座
2022-11-18 修改了一下上框，更新stl
    [上框.stl, 底座.stl]
2022-11-20 修改脚撑安装螺孔
    [rgb脚撑.stl]
2022-11-22 修改上框跟1.42风扇座干涉的问题
    [上框.stl]
2022-11-22 更新f3d文件
2022-11-26 加厚了部分薄壁
    [rgb脚撑.stl, 上框.stl, 上盖.stl]
2022-11-27 增加线性调速，在README中进一步解释
2022-11-27 针对鹏达蓝图的12k转小风扇优化了线性控制策略
2022-12-01 （忘了）给底座加螺丝，修复了底座的一个bug
    [底座.stl]
2022-12-06 新建文件夹
2022-12-06 退回一个版本
2022-12-06 更正版本
2022-12-07 能用了，我再看看
2022-12-07 加个ignore
2022-12-07 可以了用了，等会起床再来合并
2022-12-07 处理了下文件，等会合并
2022-12-07 删除了py版本风扇控制
2022-12-07 删除了py风扇jio本
2022-12-08 进行一点改动
2022-12-08 改下ignore文件
2022-12-08 修改了项目结构
2022-12-08 修改ignore
2022-12-08 修改ignore文件
2022-12-08 修改了ignore文件
2022-12-08 修改ignore文件，添加了一些文件的忽略
2022-12-09 环境有点问题，驱动需要的头文件添加不了oled项目大失败
2022-12-13 修改了底座打印的一个小bug
    [底座.stl]
2022-12-13 忘了删旧版cad文件了。。直接重推一个吧
2022-12-14 修改了一下风扇启动时间
2022-12-14 稍微修改了下座子的线槽
    [rgb脚撑.stl, 底座.stl]
2022-12-15 完成了读取config的部分
2022-12-15 删除了之前版本需要的文件
2022-12-16 修改修饰符
2022-12-16 编码有问题。。。。。
2022-12-16 我滴任务完成了
2022-12-16 删除旧版代码
2022-12-20 加了个塔方案
    [上盖.stl, 扣具.stl]
2022-12-20 修改了下参数
2022-12-25 一点小改动
    [扣具.stl, 耳朵.stl]
2022-12-31 增加了下框加高，适配了官方散热
    [上盖FE.stl, 下框加高.stl]
2023-01-12 增加了带maskrom按钮的上框，为适配官方散热模组的上盖增加了栅格
2023-01-12 修改了一点装配错误
    [maskrom按钮.stl, 上框withmaskrom按钮.stl]
2023-01-15 修改了一下控制脚本
2023-01-20 自用config
2023-01-20 更新自用config
2023-01-31 整理了stl
    [maskrom按钮.stl, rgb脚撑.stl, 上框.stl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]
2023-01-31 stl导错了重导一个
    [上盖沉头螺丝版本.stl, 下盖沉头螺丝版本.stl]
2023-02-07 上次传丢了个stl
    [下盖加高.stl]
2023-02-16 修改了一下
2023-02-16 改点小参
2023-02-24 增加了一个风扇低速区温度配置项和风扇起转温度配置项
2023-02-24 修改gitingore文件
2023-02-24 CAD更新详见Fusion360 链接
2023-02-24 进一步解释风扇脚本
2023-02-24 修个了boost的小bug
2023-02-24 对程序启动做了点优化
2023-02-24 延长了boost时间
2023-02-24 修改了最大功率算法
2023-02-24 修改示意图
2023-02-27 修改了boost的bug
2023-02-27 修了点boost的bug，还有一些小的改动
2023-02-27 修改了boost。
2023-02-28 修改了一下启动顺序
2023-02-28 小改了一下boost
